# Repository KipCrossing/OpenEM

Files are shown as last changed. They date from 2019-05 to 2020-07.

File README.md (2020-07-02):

# OpenEM Project

--------------------------------------------------------------------------------

This repository contains the Files and code related to the OpenEM project.

See [TODO.md](Info/TODO.md) for the current to do list.

Notes for the H-bridge variation of the setup may be found [here](Testing/README.md)

## Notes Summary

The following are a summary of notes in regards to the development of the OpenEM project; including the materials and methods used.

- Pyboard with micropython
- AD9833 wave generator
- 10 W amplifier
- Matching coils with RF of 17100 Hz
- Rx coil and op-amp grounded to 2.5 volts
- ADC on pyboard 0-3.3v for Rx signal
- ADC on pyboard to record wave from AD9833
- Record both waves onto buffers - x rotations and 10 samples per wave
- Get average of each n samples for all waves
- Use the curve fitting algorithm to get the amplitude and starting phase of the waves
- Calculate the phase shift of the received wave from the gen wave for reference
- Calibrate the primary wave while OpenEM is placed high above the ground
- Subtract Hp from the total input wave (Record Hp values)
- Lower OpenEM to the ground - new readings should be Hs (Amp and sft)
- Send readings to phone over Bluetooth
- Use Open Data Mapper to saves readings and GPS into a file and put coloured pin on the map
- Perform OpenEM survey on the field
- Perform Dualem survey on the field
- Smooth OpenEM data with a 7 point average
- Load data into QGIS
- Interpolate data (kriging) for the field area into rasta files (All dualem con and OpenEM con)
- Compare points of each Raster
- Make a model of Open vs 1mHCPcon & 2mHCPcon
- Discuss

Lessons learnt:

- ADC side Rx coil at the centre wire for more stable reading
- The RF of the Rx coil will change depending on what side the coil is grounded (inner or outer)
- Make coils RIGID
- put choke inductor at the 10 W amplifier to reduce noise from the amplifier
- Don't use a pre-amplifier as it changes the resonant frequency of the receiver coil
- Use a simple non inverting amplifier grounded at 2.5 volts
- Secure all cables so that they don't move
- Place received a coil at distance from the circuitry to avoid feedback noise

## PyBoard with MicroPython

There are several requirements and pre-requisites for the OpenEM project that need to be considered when deciding on the correct microcontroller. These include: High resolution and high sample rate ADC Fast processing power for complex algorithms Common interfaces including; I2C, SPI and UART to drive external hardware and sensors Rapid prototyping Expandable storage for logging The microcontroller that was chosen, as it meets the above criteria, is the PyBoard (Bell 2017). The PyBoard is based on the STM32F405RG ARM micro-processor with an operating frequency of 168 MHz. The ADC's have a 12-bit resolution a sample rate of up to 200 kHz. All common interfaces are included plus several GPIO pins. Further, the PyBoard has a micro SD card slot for expandable storage. Lastly, the PyBoard is powered by MicroPython and is ideal for rapid prototyping.

MicroPython is a Re-write of Python 3 that is designed to run on microcontrollers (reference). Further, python is a commonly used, simple programming language and, as such, is good for showcasing the methods and algorithms used when handling and analysing the data. The MicroPython code for the OpenEm project may be found [here](https://github.com/KipCrossing/OpenEM).

## AD9833 Wave Gen

The first step, after establishing what microcontroller to use, is to generate a sine wave that can be adjusted to match the resonant frequency of the transmitter and receiver coils. Therefore, it is important to select a wave generator with a variable frequency that can be adjusted via a common interface. For this, the AD9833 was selected as is has a frequency range of 0.1 Hz to 12.5 MHz (Qi et al. 2015) and can be controlled over SPI. To set the frequency and wave type (sine, square or triangle) a MicroPython library was made and can be found [here](https://github.com/KipCrossing/Micropython-AD9833). This signal is then amplified to the Transmitter coil.

## Amplifying the signal

One of the objectives with the transmitter coil it to maximise the current flowing through it. According to the law of Biot-Savart [(Pappas 1983)](https://link-springer-com.ezproxy1.library.usyd.edu.au/content/pdf/10.1007%2FBF02721552.pdf), the magnetic flux density is directly proportional to current I

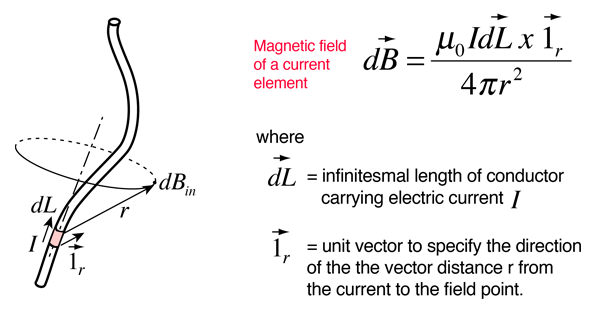
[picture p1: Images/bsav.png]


Therefore, we need an amplifier to supply the current and that will maximise the voltage to get the maximum current.

```
V = I*Z
```

Where Z is the impedance of the coil at frequency f. The working for this may be found [here](https://github.com/KipCrossing/Coil_Physics/blob/master/coil.py).

## OpenEM Frequency

The frequency needs to be chosen whilst considering the following requirements:

- The sample rate of the ADC on the PyBoard and enough samples per wave to get a precise enough estimate of the waves properties (apm and shift)
- The higher the frequency, the higher the Emf (Faraday's law)
- The larger the area of Rx the larger the Emf
- The higher the frequency, the lower the capacitive reactance
- The higher the frequency, the higher the inductive reactance
- The coil needs to have practical dimensions for the resonant frequency

The max sample rate of the pyboard using the `pyb.ADC.read_timed_multi()` method is approximately 200 kHz. The reason multiple ADC channels need to be recorded at once is so that the phase shift, in reference to the original wave (AD9833) can be observed. Further at least 10 samples per wave is deemed as acceptable to get an estimate of the wave properties. Therefore the frequency needs to be less than 20 kHz.

### Resonant Frequency

The resonant frequency of a coil is determined by:

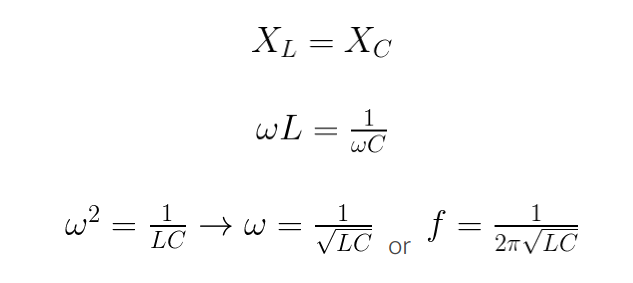
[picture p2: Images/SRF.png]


Where:

- XC = capacitive reactance
- XL = inductive reactance
- C = capacitance
- L = inductance

### Coil Details

Wound on a ferrite core, these are the details of the coil configuration:

- Wire gauge: 0.5 mm
- Coil length: 100 mm (200 turns)
- Number of layers: 20
- Total turns: 40,000
- Ferrite core diameter: 10 mm

Coil Properties:

- RF = 17,100 Hz
- L = 514.3 mH
- R = 12.6 Ohms
- C = 0.16 nF

The Resonant Frequency (**RF**) was obtained by sweeping a wave in an adjacent coil and observing where the amplitude peaked. The Coils Inductance (**L**) and Resistance (**R**) were measured using an [LCR40](https://www.peakelec.co.uk/acatalog/lcr40-atlas-lcr-meter.html). Lastly the capacitance (**C**) was back calculated using the following relation for the RF:

```
RF = 1/(2*math.pi_math.sqrt(Inductance*Capacitance)
```

From here, we may determine the Total Reactance (**Xt**) and the Impedance (**Z**) of the coils using the following equations (ref):

```
def Total_Reactance(self, freq):
  L = 2*np.pi_freq_self.coil_inductance
  C = 1/(2*np.pi_freq_self.coil_capacitance)
  return abs(C-L)

def Impedance(self, freq):
  return np.sqrt(self.coil_resistance**2 + self.Total_Reactance(freq)**2)
```

- Xt: 2913.00 Ohms
- Z = 2913.05 Ohms

Note that the Resistace (**R**) is significantly lower than the Total Reactance (**Xt**) and therefor Xt is the major contributing factor in the Impedance (**Z**). These equations may be found the the [Coil_Physics](https://github.com/KipCrossing/Coil_Physics) repo.

### Coil winding methods

In order to get the correct RF, a frequency sweep generator was set up and the frequency at which the the amplitude was the greatest is the RF. Depending on weather the frequency needs to be higher or lower, the following is done: To get it high - unwind loops. To get lower - wind more loops. Generally, more turns makes the Inductance increase which in turn, makes the makes the RF lower (see above formula for RF). Further, the length of the ferrite core is another factor contributing to the RF of a coil.

This is done with a similar set-up to what will be used in the OpenEM amplification signal. The materials and method are:

- get wave generator -
- Control AD9833 over SPI from the pyboard using this [DRIVER](https://github.com/KipCrossing/Micropython-AD9833)
- amplify the signal with a mini 10 Watt amplifier
- sweep through a range of frequencies to determine which frequency has yields the highest amplitude.

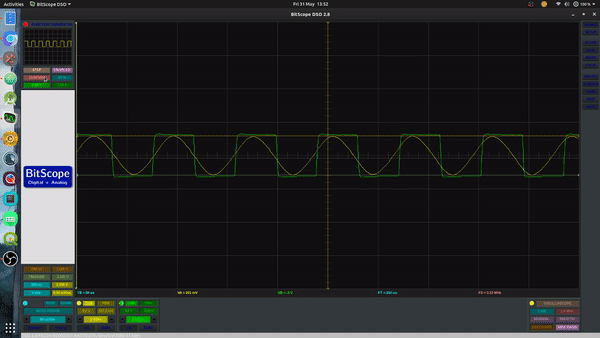
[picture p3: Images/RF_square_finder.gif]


_(insert figure for sweep f vs amp)_

_Note: For consistency, the transmitter coil and the receiver coil are identical so that the RF's are the same for both_

### Wave Generator

Once the RF has been established the wave is then amplified via simila means to how the RF was established. That is: PyBoard -> AD9833 -> AMP -> Tx coil

### Transmitter Coil

### receiver coil

## OpenEM Images

### Image of OpenEM in the field



### Image of the OpenEM being calibrated



### Map showing some example results of the OpenEM



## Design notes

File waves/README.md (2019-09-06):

# A discussion on analysing the data containing the primary and secondary waves

In this section, we will discuss approaches used to obtain our primary and secondary waves from our input data.

# Obtaining the Primary wave (Hp)

First, we obtain a list of data that is a representation of the primary wave that was obtained during calibration.

```python
Hp = [-6583,    580,    7477,    11508,    11147,    6558,    -540,    -7415,    -11523,    -11209]
```

We then approximate the Amplitude and phase shift using:

```python
import specialmath
sm = specialmath.SpecialMath()
(amp, sft) = sm.fit_sin(Hp, 5)
```

Note: the shift `sft` is relative to the transmitted wave and is observer by another ADC From these, we can generate a new the "perfect wave" using:

```python
Hp_fit = sm.gen_sin(10, amp, sft)
```

We can now get the values for the "perfect wave":

```python
>>> print(Hp_fit)
[-6570.65308724154, 550.1017952045793, 7460.736489154883, 11521.623425354583, 11181.64181864582, 6570.6530872415415,-550.1017952045727, -7460.736489154878, -11521.623425354584, -11181.641818645821]
```

And by taking the difference of the two lists, we get the noise:

```python
[-12.34691276, 29.8982048, 16.26351085, -13.62342535, -34.64181865, -12.65308724, 10.1017952, 45.73648915, -1.376574645, -27.35818135]
```

By viewing this data on a graph, it may be shown that the difference is relatively minor:

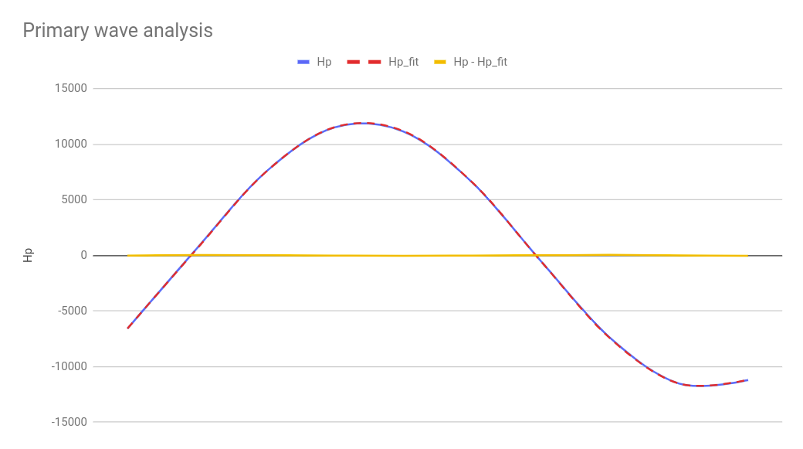
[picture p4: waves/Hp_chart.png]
Hp_chart


Now, the by subtracting the primary wave data from the input data, we should approximate to zero far away from material. When close to material, input signal

# Obtaining the Secondary wave (Hs)

## Method 1

The values of the Amplitude and Phase shift relative to the Tx signal of Hp are captured during calibration. Then when lowered to the ground for readings, a data list is created using the gen_sin() method that represents the primary wave.

```python
sm.hp = sm.gen_sin(10, sm.hp_amp, s1 + sm.hp_sft)
```

This list is then subtracted from the new input signal list (Ht) to get the list representing the secondary wave.

_Note: this method does not take into account changes in the primary signal_

## Method 2

This method requires only the phase shift (relative to the Tx signal) as a reference to the phase of the primary wave. Once the primary wave phase shift is obtained, during calibration, `sm.hp_sft` the unit vector created using the phase angle is taken to be in parallel with the Real axis on the imaginary plane. As Hs will proceed Hp by a quarter wavelength (quadrature), Hs can be taken a the vector parallel to the imaginary vector.

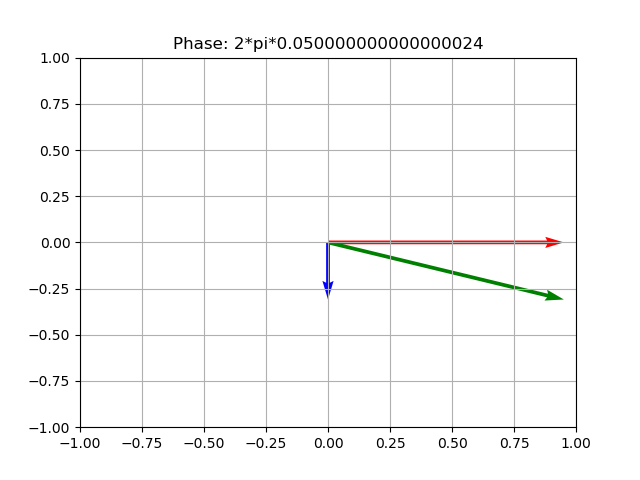
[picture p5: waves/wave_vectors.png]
wave_vector


_(Add lables etc)_

From this, Hp and Hs may easily be extracted from Ht using the trigonometric relationship:

```python
Hs = Ht*np.sin(np.pi*2*phase)
Hp = Ht*np.cos(np.pi*2*phase)
```

Where `phase` is the input phase minus the `sm.hp_sft`.

The above example may be viewed in their sinusoidal form:

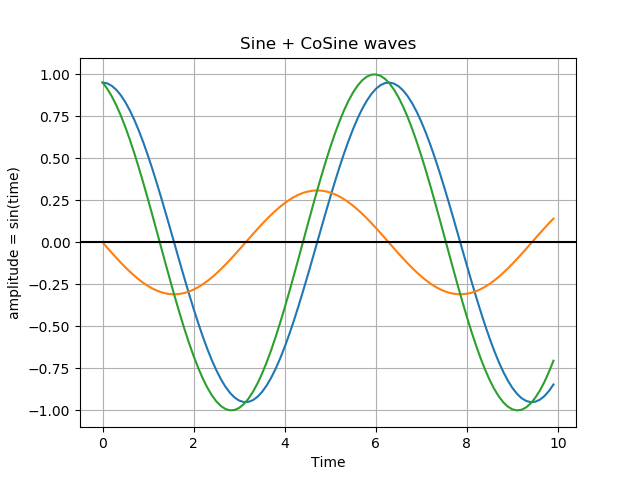
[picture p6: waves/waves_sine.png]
sine


The following formula shown the relationship between the two methods.

formula

See [REF](https://dspguru.com/files/Sum_of_Two_Sinusoids.pdf)

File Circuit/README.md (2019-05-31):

# OpenEM Circuit

This is where I will keep the Fritzing files for the OpenEM project

Version: Fritzing 0.9.3

## Notes:

Just getting started

### TODO

- Fix H-Bridge part
- coil
- Non-inverting amplifier (op amp)
- AD9833
- PyBoard
- Amplifier
- blue-tooth
- temp sensor
- voltage to ADC

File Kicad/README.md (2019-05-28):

# OpenEM Circuit

This is where I will keep the KiCad files for the OpenEM project

Version: KiCad 5.0.2

## Notes:

Just getting started

### TODO

- coil
- Non-inverting amplifier (op amp)
- AD9833
- PyBoard
- Amplifier
- blue-tooth
- temp sensor
- voltage to ADC

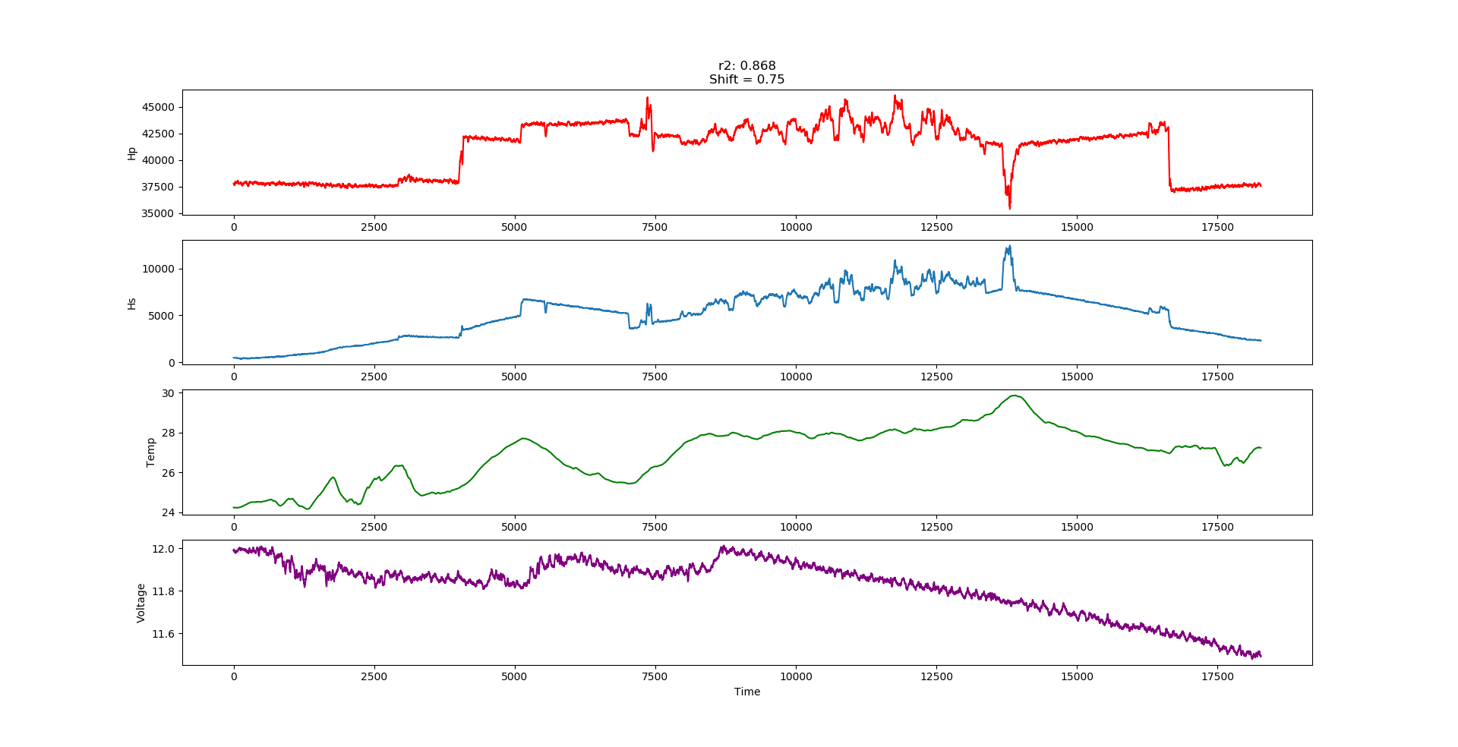
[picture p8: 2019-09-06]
Images/Cobbity9_1.png

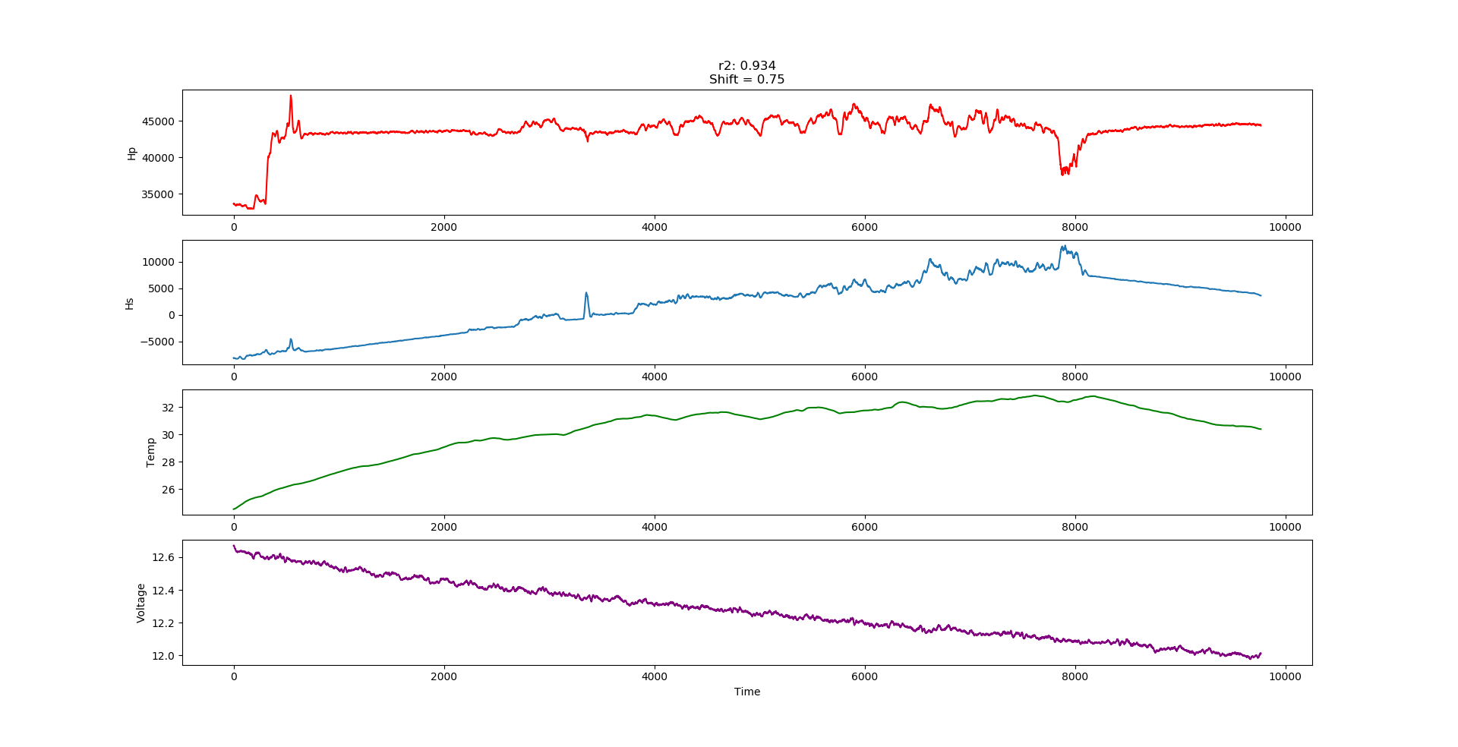
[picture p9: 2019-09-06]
Images/Cobbity9_2.png

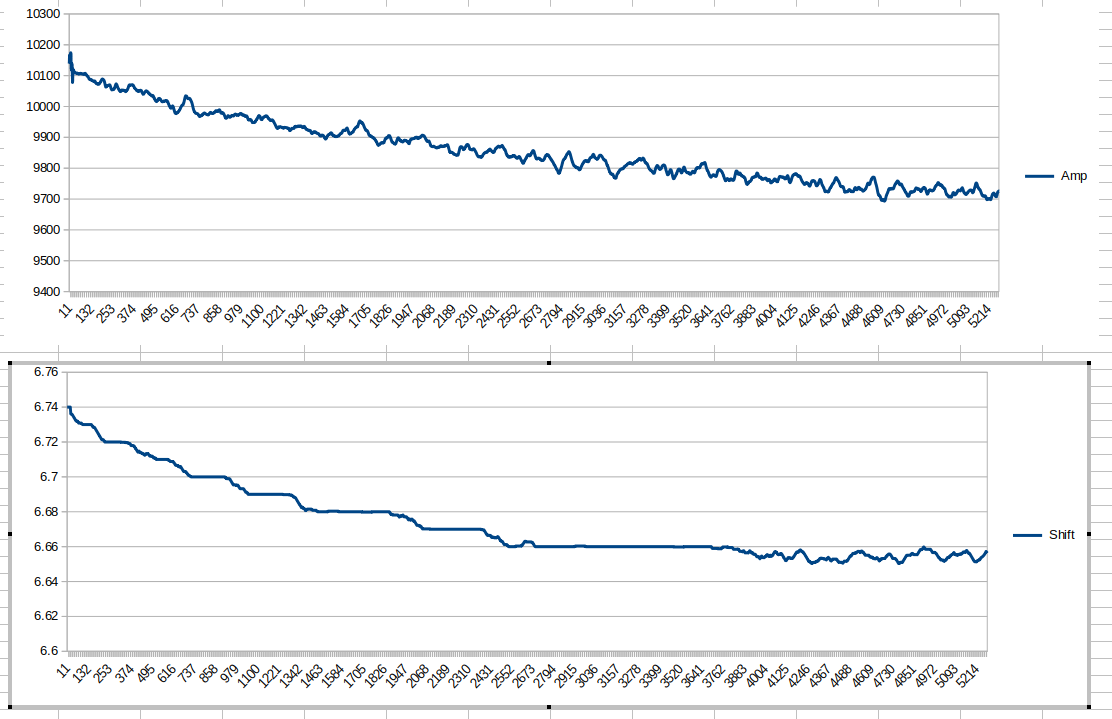
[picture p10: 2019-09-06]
waves/Screenshot from 2019-07-03 22-18-38.png

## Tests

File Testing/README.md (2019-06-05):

# Powering the Transmitter coil with a H-Bridge

This directory to keep notes on powering the Transmitter with a H-Bridge

The current set up is to keep put chokes on the 12v-in and GND-in lines of The H Bridge.

## Outcomes

- Stable input signal
- No voltage drift
- Small amount of drift (maybe noise)

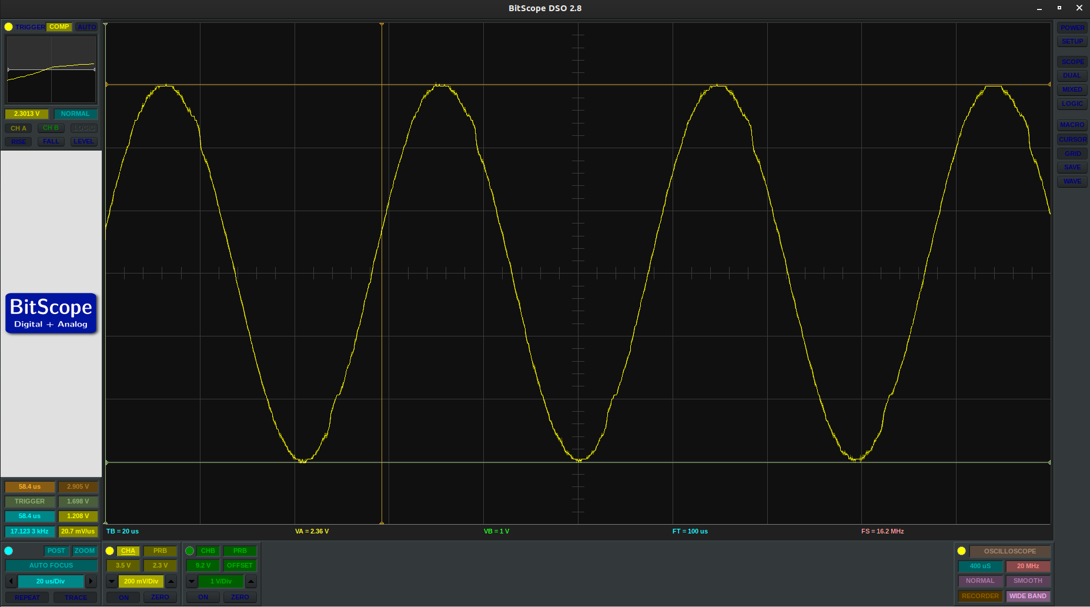
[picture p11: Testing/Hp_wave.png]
 _Input wave at calibration location_

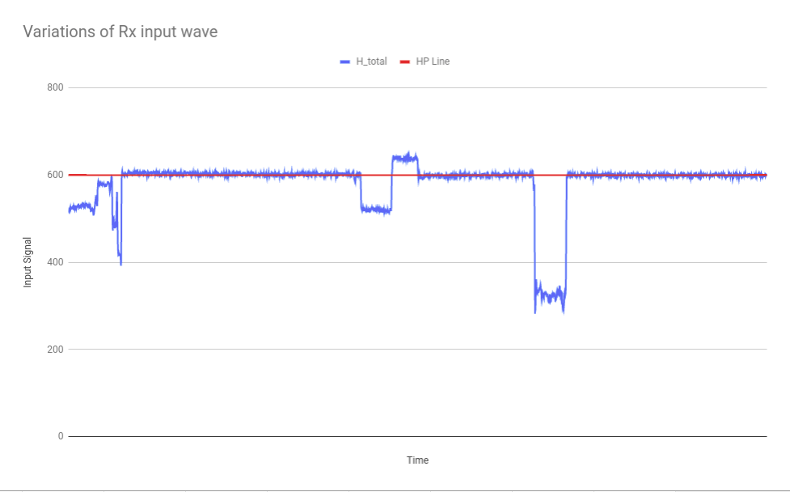
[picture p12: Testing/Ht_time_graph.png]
 _Graph showing the stability of the input signal_

There seems to be no drift in readings over a long amount of time. The standard deviation is about 2.9 for input reading average of 603.0\. _Note: these readings are directly proportional to the value from the ADC_

Notes on above image:

- Where the readings are at about 600, this is when the OpenEM is in the calibration area (no conductive material near it)
- At the beginning this is when the OpenEM is being moved from the work bench
- The 2nd and 3rd variations are at two different location (in more in phase and the other out)
- The last variation is when the oscilloscope is attached and the impedance of the input amplifier changes

Using the method on the same commit, an error occurs only **0.5%** of the time.

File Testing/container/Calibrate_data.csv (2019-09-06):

ID | Amp | Shift | Shift_out | Voltage | Temp | Humidity | Hs | Hp
0 | 39918.54 | 6.8 | 0.4000001 | 11.65521 | 25.56344 | 40.50965 | 9927.341 | 38664.42
1 | 39235.32 | 6.82 | 0.4199996 | 11.73105 | 25.53406 | 40.53407 | 10234.19 | 37877.06
2 | 39817.23 | 6.81 | 0.4099998 | 11.67589 | 25.51804 | 40.589 | 10144.26 | 38503.32
3 | 39831.0 | 6.82 | 0.4200001 | 11.71726 | 25.47532 | 40.62562 | 10389.58 | 38452.12
4 | 39538.26 | 6.81 | 0.4099998 | 11.73105 | 25.41924 | 40.70344 | 10073.19 | 38233.55
5 | 38959.41 | 6.81 | 0.4099998 | 11.66899 | 25.40589 | 40.75838 | 9925.714 | 37673.81
6 | 39249.6 | 6.82 | 0.4199996 | 11.71036 | 25.37919 | 40.78432 | 10237.92 | 37890.85
7 | 39581.61 | 6.820001 | 0.4200006 | 11.67589 | 25.33646 | 40.87587 | 10324.54 | 38211.36
8 | 39159.84 | 6.820001 | 0.4200006 | 11.67589 | 25.30709 | 40.90028 | 10214.53 | 37804.19
9 | 39208.8 | 6.809999 | 0.4099994 | 11.70347 | 25.23766 | 41.0193 | 9989.239 | 37914.97
10 | 39835.59 | 6.81 | 0.4099998 | 11.65521 | 25.19493 | 41.05592 | 10148.94 | 38521.07
11 | 39629.04 | 6.81 | 0.4099998 | 11.71036 | 25.13885 | 41.13375 | 10096.32 | 38321.34
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

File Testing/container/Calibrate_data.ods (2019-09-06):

ID | Amp | Shift | Shift_out | Voltage | Temp | Humidity | Hs | Hp | Hs | Hp | TempAdj |  | HsAdj | 6.8
0 | 39918.54 | 6.8 | 0.4000001 | 11.65521 | 25.56344 | 40.50965 | 9927.341 | 38664.42 | 0 | 39918.54 | 0 | 0 | 0
1 | 39235.32 | 6.82 | 0.4199996 | 11.73105 | 25.53406 | 40.53407 | 10234.19 | 37877.06 | 493.032595956114 | 39232.2221440709 | -0.02938 | -12.3058830036168 | 529.950244966964
2 | 39817.23 | 6.81 | 0.4099998 | 11.67589 | 25.51804 | 40.589 | 10144.26 | 38503.32 | 250.17738839979 | 39816.4440419688 | -0.045400000000001 | -19.0158981744118 | 307.225082923025
3 | 39831 | 6.82 | 0.4200001 | 11.71726 | 25.47532 | 40.62562 | 10389.58 | 38452.12 | 500.517934593829 | 39827.8551116822 | -0.08812 | -36.9092719631969 | 611.24575048342
4 | 39538.26 | 6.81 | 0.4099998 | 11.73105 | 25.41924 | 40.70344 | 10073.19 | 38233.55 | 248.424579727718 | 39537.4795485978 | -0.144200000000001 | -60.3985135848053 | 429.620120482134
5 | 38959.41 | 6.81 | 0.4099998 | 11.66899 | 25.40589 | 40.75838 | 9925.714 | 37673.81 | 244.787581843254 | 38958.6409746012 | -0.157550000000001 | -65.9901928938004 | 442.758160524655
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

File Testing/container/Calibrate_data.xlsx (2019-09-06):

ID | Amp | Shift | Shift_out | Voltage | Temp | Humidity | Hs | Hp | Hs | Hp | TempAdj |  | HsAdj | 6.8
0 | 39918.54 | 6.8 | 0.4000001 | 11.65521 | 25.56344 | 40.50965 | 9927.341 | 38664.42 | 0 | 39918.54 | 0 | 0 | 0
1 | 39235.32 | 6.82 | 0.4199996 | 11.73105 | 25.53406 | 40.53407 | 10234.19 | 37877.06 | 493.032596 | 39232.22214 | -0.02938 | -12.305883 | 529.950245
2 | 39817.23 | 6.81 | 0.4099998 | 11.67589 | 25.51804 | 40.589 | 10144.26 | 38503.32 | 250.1773884 | 39816.44404 | -0.0454 | -19.01589817 | 307.2250829
3 | 39831 | 6.82 | 0.4200001 | 11.71726 | 25.47532 | 40.62562 | 10389.58 | 38452.12 | 500.5179346 | 39827.85511 | -0.08812 | -36.90927196 | 611.2457505
4 | 39538.26 | 6.81 | 0.4099998 | 11.73105 | 25.41924 | 40.70344 | 10073.19 | 38233.55 | 248.4245797 | 39537.47955 | -0.1442 | -60.39851358 | 429.6201205
5 | 38959.41 | 6.81 | 0.4099998 | 11.66899 | 25.40589 | 40.75838 | 9925.714 | 37673.81 | 244.7875818 | 38958.64097 | -0.15755 | -65.99019289 | 442.7581605
6 | 39249.6 | 6.82 | 0.4199996 | 11.71036 | 25.37919 | 40.78432 | 10237.92 | 37890.85 | 493.212039 | 39246.50102 | -0.18425 | -77.17355151 | 724.7326935
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

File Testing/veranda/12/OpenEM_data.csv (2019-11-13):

ID | Amp | Shift | Shift_out | Voltage | Temp | Humidity | CoreTemp | Hs | Hp | Wmean
0 | 3093.811 | 8.15202 | 5.639081 | 13.06888 | 21.1761 | 39.52544 | 42.16 | 2847.722 | -1209.192 | 1295754.0
1 | 3764.885 | 9.6021 | 7.089162 | 13.07922 | 21.16274 | 39.41253 | 41.84 | 961.0996 | -3640.144 | 1296248.0
2 | 3399.86 | 8.56574 | 6.052801 | 13.07922 | 21.14672 | 39.30114 | 41.52 | 2682.745 | -2088.524 | 1296351.0
3 | 1104.803 | 2.21205 | 9.699111 | 13.0344 | 21.14672 | 39.30114 | 42.16 | -1085.118 | -207.6253 | 1296639.0
4 | 1618.813 | 6.835979 | 4.323041 | 13.04819 | 21.10666 | 39.23857 | 42.16 | 1474.571 | 667.9803 | 1296315.0
5 | 2727.046 | 4.585959 | 2.073021 | 13.04819 | 21.10666 | 39.22484 | 41.84 | -722.8647 | 2629.495 | 1296087.0
6 | 3129.389 | 4.76785 | 2.254911 | 13.07577 | 21.10666 | 39.12871 | 41.52 | -480.0041 | 3092.357 | 1296502.0
7 | 2740.987 | 4.79571 | 2.282771 | 13.0413 | 21.07729 | 39.12718 | 41.52 | -372.954 | 2715.495 | 1296022.0
8 | 2324.494 | 4.970399 | 2.45746 | 13.04819 | 21.07729 | 39.11345 | 41.52 | -62.12305 | 2323.664 | 1296860.0
9 | 2307.032 | 5.28468 | 2.771741 | 13.07922 | 21.05058 | 39.234 | 41.84 | 391.9917 | 2273.486 | 1296534.0
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

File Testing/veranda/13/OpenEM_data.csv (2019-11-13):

ID | Amp | Shift | Shift_out | Voltage | Temp | Humidity | CoreTemp | Hs | Hp | Wmean | Freq
0 | 205577.8 | 2.43354 | 9.93354 | 13.48944 | 22.07599 | 56.84902 | 37.36 | -8582.002 | -205398.6 | 1304183.0 | 9235
1 | 205699.4 | 2.433059 | 9.93306 | 13.48255 | 22.03326 | 56.87648 | 38.0 | -8649.111 | -205517.5 | 1304486.0 | 9235
2 | 205766.4 | 2.432511 | 9.93251 | 13.51357 | 22.04929 | 56.85665 | 38.32 | -8722.801 | -205581.5 | 1304225.0 | 9235
3 | 205591.9 | 2.43162 | 9.93162 | 13.47566 | 22.03326 | 56.85359 | 39.28 | -8830.39 | -205402.2 | 1304625.0 | 9235
4 | 205541.9 | 2.43119 | 9.93119 | 13.48255 | 22.04929 | 56.87953 | 39.6 | -8883.665 | -205349.8 | 1304484.0 | 9235
5 | 205433.4 | 2.431689 | 9.931689 | 13.51357 | 22.04929 | 56.86733 | 39.6 | -8814.677 | -205244.2 | 1304796.0 | 9235
6 | 205436.4 | 2.43169 | 9.93169 | 13.46187 | 22.04929 | 56.87953 | 39.92 | -8814.61 | -205247.2 | 1304500.0 | 9235
7 | 205567.6 | 2.43043 | 9.93043 | 13.48255 | 22.04929 | 56.86733 | 40.24 | -8982.806 | -205371.3 | 1304882.0 | 9235
8 | 205511.4 | 2.4321 | 9.9321 | 13.47566 | 22.03326 | 56.88869 | 40.24 | -8764.958 | -205324.4 | 1304654.0 | 9235
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

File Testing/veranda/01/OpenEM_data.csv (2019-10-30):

ID | Amp | Shift | Shift_out | Voltage | Temp | Humidity | CoreTemp | Hs | Hp | Wmean
0 | 132.6416 | 6.94161 | 4.638036 | 13.55839 | 25.99603 | 34.57542 | 44.08 | 29.90711 | -129.226 | 1310730.0
1 | 130.0739 | 5.19838 | 2.894806 | 13.58252 | 25.98268 | 34.55863 | 43.44 | 126.0923 | -31.93674 | 1310616.0
2 | 96.08691 | 4.9129 | 2.609326 | 13.60665 | 25.98268 | 34.55863 | 44.08 | 95.86032 | -6.595168 | 1310779.0
3 | 129.8579 | 0.9792199 | 8.675646 | 13.48944 | 25.98268 | 34.5861 | 44.08 | -96.01147 | 87.43502 | 1310627.0
4 | 113.9455 | 4.56076 | 2.257186 | 13.60665 | 25.96933 | 34.6273 | 44.4 | 112.622 | 17.3167 | 1310816.0
5 | 214.7823 | 4.67806 | 2.374486 | 13.45842 | 25.98268 | 34.5861 | 44.08 | 214.1148 | 16.92077 | 1310611.0
6 | 249.1355 | 4.84638 | 2.542806 | 13.46187 | 25.96933 | 34.57084 | 44.08 | 249.0454 | -6.699862 | 1310809.0
7 | 274.9135 | 5.04029 | 2.736716 | 13.44118 | 25.96933 | 34.59983 | 44.08 | 271.8783 | -40.73813 | 1310554.0
8 | 141.8548 | 5.62267 | 3.319096 | 13.43429 | 25.96933 | 34.5861 | 44.08 | 123.4794 | -69.82563 | 1310789.0
9 | 328.9684 | 4.9389 | 2.635326 | 13.53771 | 25.95331 | 34.61204 | 44.08 | 327.78 | -27.93775 | 1310612.0
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

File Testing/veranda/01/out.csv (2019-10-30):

i0 | i1 | i2 | i3 | i4 | i5 | i6 | i7 | i8 | i9
9261.001 | 17893.0 | 19844.0 | 14236.0 | 3019.0 | -9275.001 | -18043.0 | -19818.0 | -14115.0 | -3002.0
19314.25 | 12485.25 | 693.25 | -11342.75 | -18921.75 | -19285.75 | -12417.75 | -643.75 | 11221.25 | 18897.25
1557.625 | 13301.63 | 19623.62 | 18497.62 | 10419.63 | -1775.375 | -13207.37 | -19502.37 | -18494.38 | -10420.37
-14897.75 | -19971.75 | -17557.75 | -8245.749 | 4082.25 | 14816.25 | 19811.25 | 17514.25 | 8466.25 | -4016.75
16218.75 | 6191.75 | -6371.25 | -16465.25 | -20143.25 | -16265.25 | -6021.25 | 6466.75 | 16363.75 | 20024.75
-8532.75 | -17605.75 | -19966.75 | -14718.75 | -3885.75 | 8480.25 | 17578.25 | 20061.25 | 14715.25 | 3875.25
19448.87 | 13014.87 | 1435.875 | -10611.13 | -18645.12 | -19442.12 | -12988.13 | -1382.125 | 10615.87 | 18552.87
969.75 | 12689.75 | 19353.75 | 18673.75 | 11001.75 | -887.2499 | -12572.25 | -19318.25 | -18784.25 | -11126.25
-19785.25 | -17916.25 | -8981.25 | 3344.75 | 14430.75 | 19847.75 | 17683.75 | 8997.75 | -3254.25 | -14368.25
-6847.75 | 5610.25 | 15725.25 | 20075.25 | 16784.25 | 6873.25 | -5716.75 | -16000.75 | -19955.75 | -16547.75
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

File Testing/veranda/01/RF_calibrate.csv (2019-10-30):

Freq | Amp | Shift | tim_freq | temp
9220 | 166257 | 2.298 | 92206.36 | 26.02541
Hp | 166204.4 | 2.303574

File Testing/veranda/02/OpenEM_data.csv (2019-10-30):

ID | Amp | Shift | Shift_out | Voltage | Temp | Humidity | CoreTemp | Hs | Hp | Wmean
0 | 250.8576 | 8.78389 | 6.500241 | 13.55839 | 24.63416 | 33.38522 | 44.72 | -202.9704 | -147.4197 | 1312474.0
1 | 61.337 | 4.63857 | 2.354922 | 13.56528 | 24.63416 | 33.38522 | 44.72 | 61.08234 | 5.583465 | 1312367.0
2 | 132.7418 | 6.99278 | 4.709131 | 13.53081 | 24.63416 | 33.3547 | 44.72 | 24.12483 | -130.5311 | 1312556.0
3 | 127.7085 | 1.491201 | 9.207553 | 13.53771 | 24.64751 | 33.3547 | 44.4 | -60.99224 | 112.2026 | 1312399.0
4 | 210.2226 | 2.601511 | 0.3178623 | 13.56873 | 24.63416 | 33.3547 | 44.4 | 41.70683 | 206.0438 | 1312497.0
5 | 188.2393 | 1.40524 | 9.121592 | 13.5446 | 24.63416 | 33.36843 | 44.4 | -98.69827 | 160.2894 | 1312341.0
6 | 459.9802 | 0.1581001 | 7.874452 | 13.52047 | 24.63416 | 33.33944 | 44.72 | -447.3079 | 107.2261 | 1312706.0
7 | 185.7681 | 3.06568 | 0.782032 | 13.38603 | 24.60479 | 33.41268 | 44.72 | 87.65098 | 163.7898 | 1312322.0
8 | 146.9707 | 0.0606184 | 7.77697 | 13.42739 | 24.60479 | 33.36691 | 44.72 | -144.7508 | 25.44775 | 1312456.0
9 | 357.5709 | 0.8608294 | 8.577181 | 13.40671 | 24.59144 | 33.3959 | 44.72 | -278.7526 | 223.9507 | 1312241.0
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

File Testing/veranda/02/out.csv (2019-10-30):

i0 | i1 | i2 | i3 | i4 | i5 | i6 | i7 | i8 | i9
-4994.625 | 7429.375 | 16906.37 | 19952.37 | 15206.38 | 4780.375 | -7473.625 | -16869.63 | -19712.62 | -15224.62
-17967.88 | -19694.87 | -13779.88 | -2591.875 | 9616.125 | 17990.12 | 19471.12 | 13644.12 | 2717.125 | -9403.875
12062.88 | 424.875 | -11456.12 | -18859.12 | -19002.12 | -12054.13 | -470.125 | 11297.87 | 18843.87 | 19211.87
12963.87 | 19494.87 | 18394.87 | 10251.87 | -1890.125 | -13220.12 | -19447.12 | -18224.12 | -10192.12 | 1867.875
-17427.37 | -8199.375 | 4128.625 | 14717.62 | 19768.62 | 17243.62 | 8292.624 | -3950.375 | -14745.37 | -19828.37
6164.875 | 16113.87 | 19886.87 | 16119.87 | 6105.875 | -6218.125 | -16127.12 | -19892.12 | -16017.12 | -6137.125
-19739.75 | -14719.75 | -3985.75 | 8410.251 | 17412.25 | 19825.25 | 14479.25 | 3938.25 | -8252.749 | -17366.75
1762.25 | -10276.75 | -18342.75 | -19478.75 | -13099.75 | -1697.75 | 10378.25 | 18446.25 | 19446.25 | 12863.25
19193.25 | 18736.25 | 11182.25 | -571.75 | -12028.75 | -19121.75 | -18793.75 | -11396.75 | 594.25 | 12206.25
-9368.0 | 2844.0 | 13869.0 | 19707.0 | 17804.0 | 9245.0 | -2849.0 | -13827.0 | -19547.0 | -17878.0
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

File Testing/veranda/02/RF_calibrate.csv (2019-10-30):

Freq | Amp | Shift | tim_freq | temp
9220 | 165968 | 2.286 | 92206.36 | 24.66087
Hp | 166205.2 | 2.283648

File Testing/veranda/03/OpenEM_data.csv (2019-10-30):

ID | Amp | Shift | Shift_out | Voltage | Temp | Humidity | CoreTemp | Hs | Hp | Wmean
0 | 242.0164 | 5.50236 | 3.103526 | 13.30329 | 23.60609 | 34.03983 | 41.52 | 89.59044 | 224.8232 | 1305137.0
1 | 91.61942 | 7.97645 | 5.577615 | 13.32397 | 23.60609 | 33.99863 | 41.2 | 85.6515 | -32.52596 | 1304788.0
2 | 498.5015 | 4.225551 | 1.826716 | 13.38947 | 23.62211 | 33.98489 | 41.52 | -204.6505 | 454.5568 | 1304899.0
3 | 503.3307 | 1.88478 | 9.485946 | 13.35155 | 23.60609 | 34.01236 | 42.16 | -477.3037 | -159.7587 | 1304811.0
4 | 510.2356 | 3.07953 | 0.6806953 | 13.35155 | 23.59274 | 34.00931 | 41.52 | -464.2761 | 211.632 | 1305049.0
5 | 413.9471 | 9.240601 | 6.841766 | 13.31708 | 23.57939 | 33.98184 | 41.52 | 166.3616 | -379.0462 | 1304775.0
6 | 341.6931 | 4.78344 | 2.384605 | 13.4136 | 23.59274 | 34.00931 | 41.52 | -24.7527 | 340.7954 | 1304981.0
7 | 402.8098 | 2.53332 | 0.1344852 | 13.35155 | 23.56603 | 33.99405 | 41.84 | -401.3726 | 33.99677 | 1304756.0
8 | 210.1019 | 4.266981 | 1.868146 | 13.39292 | 23.55001 | 34.03525 | 41.52 | -81.23772 | 193.7608 | 1305026.0
9 | 291.6549 | 5.44567 | 3.046835 | 13.35155 | 23.55001 | 34.00778 | 42.16 | 98.24876 | 274.6084 | 1304630.0
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

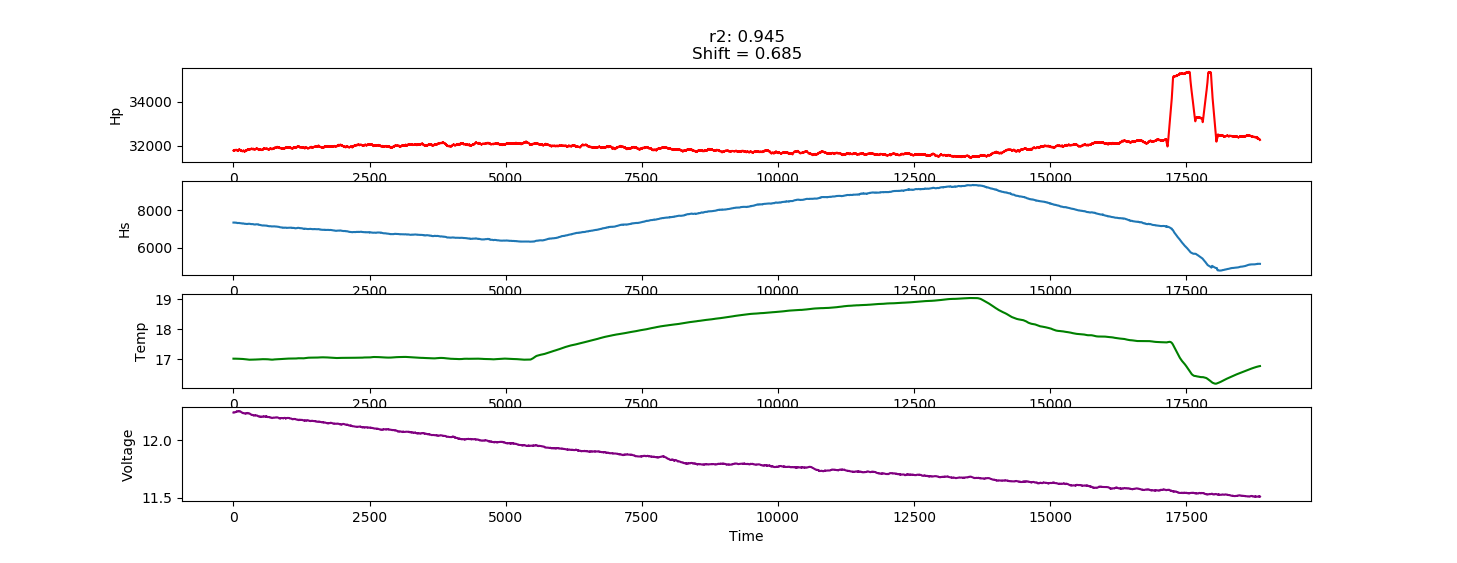
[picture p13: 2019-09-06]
Testing/Temp/Temp_test4_6.85.png

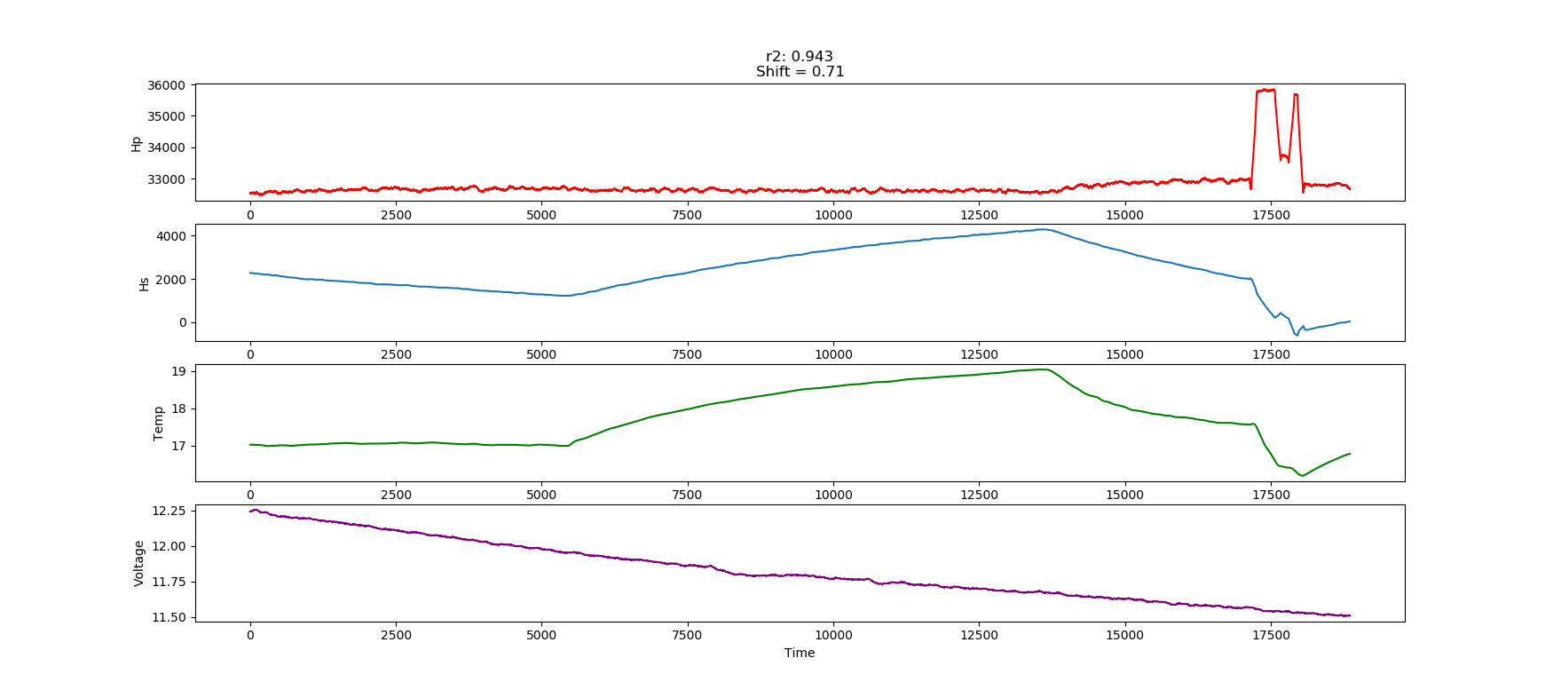
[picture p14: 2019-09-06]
Testing/Temp/Temp_test4_7.5.png

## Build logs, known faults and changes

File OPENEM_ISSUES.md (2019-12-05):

# Design Issues of the OpenEM

The following is a brief statement explaining issues that have arisen during my research into designing the OpenEM; a Low-Cost EMI sensor.

## Intro

The basic idea of electromagnetic induction (EMI) frequency domain (FD) sensors is that a sinusoidal current is introduced into a coil that produces a magnetic field (Ampere's Law) whose magnitude is sinusoidal and therefore produces an electric field (maxwell-faraday equation) that causes eddy currents to be induced in nearby mediums (due to the electromotive force and the electrical resistance of medium). These sinusoidal eddy currents produce a secondary magnetic field that precedes the first (primary) magnetic field by 90 degrees and is said to be in quadrature. Both changing magnetic fields induce an electromotive force (measured in volts) in a second coil (receiver coil) which forms the basis of the input signal.



_Image 1: sine waves of the primary (green) and secondary (orange) signals_



_Image 2: vectors of the primary (red) and secondary (purple) signals_

The input signal is then separated into the primary wave and the secondary wave via quadrature demodulation. The secondary wave is used to calculate the apparent electrical conductivity (ECa) via McNeil's equation and will be inversely proportional to the electrical resistivity of the nearby medium. Changes in the primary wave are proportional to changes in the magnetic susceptibility of the nearby medium; as the relative permeability of the medium impacts the magnetic field. The 'depth of penetration', which is an estimate of the average depth of the origins of the secondary magnetic field, is determined by the geometry of both coils in relation to each other and the nearby medium (in our case, the ground). With common configurations (eg; horizontal and vertical dipole) the depth of penetration of proportional to the intercoil spacing (distance between the transmitter and receiver coil).

## Current Setup

I wanted to start with using a vertical dipole configuration as it is the most basic and has been shown to have the largest depth of penetration (0.7*intercoil spacing). For precision agricultural purposes the intercoil spacing is required to be at least 1m to get subsoil measurements. When the intercoil spacing is small, the magnetic field strength at the receiver coil is large, however, when the intercoil spacing is increased, the magnetic field decreases exponentially in relation to the [Biot-Savart Law](Images/bsav.png).

Although electrical signals can be amplified, if they are much lower than electrical noise (environmental and instrumental) techniques must be employed to overcome the low signal to noise ratio. I used a range of techniques, including analogue and digital filter, using ferrite cores, curve fitting algorithms and operating at the coils resonant frequency. I ran a field survey and got an r2 of 74.5% and concluded that I was on the right track; [see here for results](https://github.com/KipCrossing/EMI_Field).

## Issues and Theorizing

The problems started to arise when changes in temperature would directly affect the outputs (problem 1). Although this can be expected, the variations were large and irregular. My theory is that the variations in temperature change the permeability of the ferrite coil core. This change in permeability affects the induction of the coil which in turn affects the resonant frequency of the coil. Therefore, the magnitude of the input signal may increase or decrease depending on whether the resonant frequency is higher or lower than the operating frequency. A temperature sensor was placed near the receiver coil in an attempt to identify a relationship between the change in temperature and the variations in input signal magnitude. During data collection, I noticed that the reading would change simply by being near the OpenEM or if the OpenEM was near plants. After months of investigation, I concluded that it was due to an electrical field that is present due to an electrical potential of the Transmitter coil, as the varies from peak to peak, and the grounded receiver coil (problem 2). As the OpenEM passes close by plants, the electric field lines are redirected through the plants as they have a higher permittivity than air. In an attempt to stop presence of the electric field, I created Faraday cages to surround each coil. Now, when placed near organic matter (plants, trees), there are no variations. I continued to work on the temperature problem.

It was found that for the relationship between temperature and input signal magnitude to be found, a large amount of data is required; [see here](/Testing/).

Due to the complex relationship between temperature and input signal magnitude, a model was extremely difficult to be established. I had a chat with a professor from the physics department who suggested that the operating frequency should be far away from the resonant frequency such that the relationship between temperature and the resonant frequency is significantly more linear then operating near the resonant frequency. The problem with this technique is that the signal-to-noise ratio would decrease below practical levels.

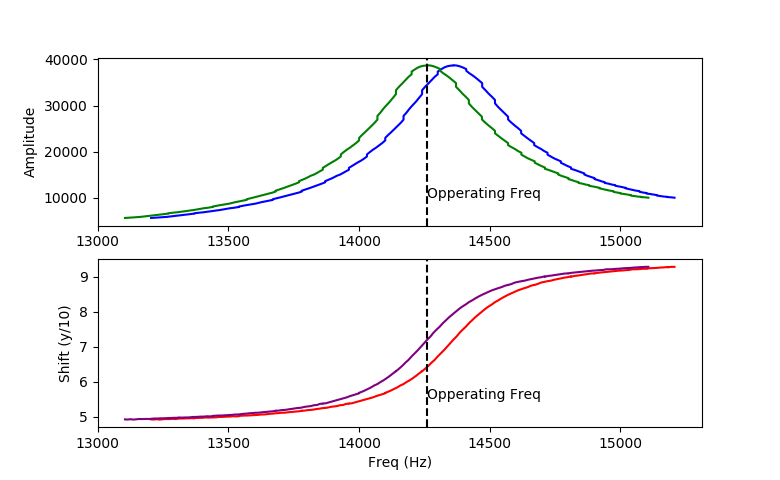
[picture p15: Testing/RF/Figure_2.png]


Further, during constant temperatures, when low into the ground and the secondary field is extracted via quadrature demodulation, the variations in the secondary field were significantly small; Much smaller than that which is predicted via McNeil's equation. This observation led me to believe that the Faraday cages were insufficient in preventing an electric field between the transmitter and receiver coils. Although the Faraday cages did stop variations in the electric field, they didn't stop the presence of an electric field. Instead, the electric field is redirected through the timber frame, as timber has a permeability 4 to 6 times greater than air.



## Closing Remarks

I'm sure there are more techniques and methods for reducing the electric field strength (ie through the use of dielectric materials), however this is far outside my field of expertise. In order to solve these problems, an in-depth knowledge of the permeability and permittivity of materials and tools to detect electric and magnetic fields are required; both of which I do not have. I would need to start practising a whole new discipline of practical physics.

Lastly, my initial assumptions did not consider the presence of an electric field. Therefore, when designing the transmitter coil, a large number of turns was assumed to be desirable as it is proportional to the magnetic field strength. However, the number of turns is also proportional to the electric field strength. I would have to redesign the transmitter coil to account for this.

Considering the small time frame until the due date of my thesis, the gaps in my knowledge and tooling and realistic potential for further unforeseen challenges, I have decided to discontinue work on this project, put it on the shelf and terminate my PhD.

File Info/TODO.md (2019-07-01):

# TO DO LIST

- [x] Wind coil for 17100 Hz
- [x] Use RF circuit to check RF
- [ ] Make it 12 SPW
- [ ] Check both amplifiers (easy connect)
- [ ] Check different sweeps
- [ ] Output max and min ADC readings
- [x] Measure voltage [circuit](https://startingelectronics.org/articles/arduino/measuring-voltage-with-arduino/)

- [ ] Show Hp vs freq graph (For 17100 Hz coil)

- [ ] Get data for `Ht - Hp = Hs` curves

- [ ] Add temperature sensor: [BME280](https://github.com/catdog2/mpy_bme280_esp8266)

- [ ] Do Hp vs temp

- [ ] Do voltage vs Hp test & find relationship

- [ ] Find temp relationship

- [ ] Do Hs vs temp

- [ ] Large Cobbity test

- [ ] Larger field test with ECe (Cores)

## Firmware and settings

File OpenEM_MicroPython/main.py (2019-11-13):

import sht31
import machine
import pyb
import array
import math
import utime
from pyb import Pin, Timer
from ad9833 import AD9833
from pyb import Pin
from pyb import SPI
from specialmath import SpecialMath


print("(Main program started)")


blueled = pyb.LED(4)
greenled = pyb.LED(1)

# Wave gen
ss = Pin('Y5', Pin.OUT_PP)
spi = SPI(2, SPI.MASTER, baudrate=9600, polarity=1, phase=0, firstbit=SPI.MSB)
wave = AD9833(spi, ss)

# Bluetooth
blue_uart = pyb.UART(6, 9600)
blue_uart.init(9600, bits=8, stop=1, parity=None)

# Temp sensor
SCLpin = 'Y9'
SDApin = 'Y10'
i2c = machine.I2C(sda=machine.Pin(SDApin), scl=machine.Pin(SCLpin), freq=400000)
sht31sensor = sht31.SHT31(i2c)


# Initial variables
spw = 10        # Samples per wave
WAVES = 500      # Number of waves to take an average from
freq = 9000    # Frequency in Hz

# send wave
wave.set_freq(freq)
wave.set_type(0)
wave.send()

# check temp sensor
sht31_t, sht31_h = sht31sensor.get_temp_humi()

wait = True
while wait:
    print('Blue Out:')
    if b'BTM-U' == blue_uart.read():
        print("Start")
        wait = False
    pyb.delay(1000)


# pyb.repl_uart(blue_uart)

blue_uart.write("Warming up!\n")


blue_uart.write("Started")


utime.sleep(2)

wave.set_freq(freq)
wave.set_type(0)
wave.send()


# Timers for ADC's
adc1 = pyb.ADC(pyb.Pin.board.Y11)  # create an ADC on pin X11
adc2 = pyb.ADC(pyb.Pin.board.X4)  # create an ADC on pin X4

adc_voltage = pyb.ADC(pyb.Pin.board.Y12)

voltage = (adc_voltage.read()/4096)*14.12


adcall = pyb.ADCAll(12, 0x70000)  # 12 bit resolution, internal channels
coretemp = adcall.read_core_temp()

# tim = pyb.Timer(8, freq=200000)        # Create timer
# buf1 = bytearray(WAVES*spw)  # create a buffer
# buf2 = bytearray(WAVES*spw)  # create a buffe
# # read analog values into buffers at 100Hz (takes one second)
# pyb.ADC.read_timed_multi((adc1, adc2), (buf1, buf2), tim)


sm = SpecialMath()

(sm.hp_amp, sm.hp_sft) = (0, 0)

# Output File
outfile = open('out.csv', 'w')
outfile.write("i0,i1,i2,i3,i4,i5,i6,i7,i8,i9,\n")
outfile.close()


def record(f, tim):
    # tim = pyb.Timer(8, freq=f*spw)        # Create timer
    # bytearray(WAVES*spw)  # create a buffer
    buf1 = array.array('H', (0 for i in range(WAVES*spw)))
    buf2 = array.array('H', (0 for i in range(WAVES*spw)))  # create a buffe
    # read analog values into buffers at 100Hz (takes one second)

    tcheck = pyb.ADC.read_timed_multi((adc1, adc2), (buf1, buf2), tim)
    # print(tcheck)

    listc = []

    for i in range(spw):
        listc.append(0)
    count = 0
    for n in range(len(buf1)):
        if count > spw-1:
            count = 0
        listc[count] += buf1[n]
        count += 1
    buf1 = None
    listd = []
    for i in range(spw):
        listd.append(0)
    count = 0
    for n in range(len(buf2)):
        if count > spw-1:
            count = 0
        listd[count] += buf2[n]
        count += 1
    # (a,s) = sm.fit_sin(listd,6)
    buf1 = None
    (a1, s1) = sm.fit_sin(listc, 6)
    # print("-")
    data_mean = sm.mean(listd)
    # print(data_mean)
    for d in range(0, len(listd)):
        listd[d] -= data_mean

    # total wave - Hp to get Hs
    if sm.hp_amp:
        sm.hp = sm.gen_sin(10, sm.hp_amp, s1 + sm.hp_sft)
        listout = [x - y for x, y in zip(listd, sm.hp)]
    else:
        listout = listd
    # print(listout)
    # outtext = ''
    # for d in listout:
    #     outtext += str(d)+','
    # outfile = open('out.csv', 'a')
    # outfile.write(outtext+"\n")
    # outfile.close()

    (a2, s2) = sm.fit_sin(listout, 6)
    # print(listout)
    # print('Hp - Amp: %f  Sft: %f' % (a1,s1))
    # print('Hs - Amp: %f  Sft: %f' % (a2,s2))
    # print(s2-s1)

    if s2-s1 < 0:
        return(a1, a2, s2-s1 + spw, data_mean)
    else:
        return(a1, a2, s2-s1, data_mean)


'''
outfile = open('RF_calibrate.csv', 'w')
outfile.write("Freq,Amp,Shift,tim_freq,temp,meanW\n")
outfile.close()

while True:
    step_list = [1000, 100, 10, 1]
    mid = 9000
    max_amp = 0
    max_freq = 0
    max_sft = 0
    tim_freq = 1
    target_sft = 100
    RF_range_file = open("FR_range.csv", 'w')
    RF_range_file.write("Freq,Amp,Shift\n")
    for step in step_list:
        for i in range(-5, 6):
            f = mid + i*step
            if step != 1 and step != 2:
                tim = pyb.Timer(8, freq=f*spw)
                freq = int(tim.freq()/float(spw))
            else:
                freq = f
            wave.set_freq(freq)
            wave.send()
            pyb.delay(50)
            greenled.toggle()
            # blue_uart.write("Checking: {}\n".format(freq))
            ampl = []
            sftl = []
            ml = []
            for j in range(4):
                (or_amp, amp, sft, m) = record(freq, tim)
                ampl.append(amp)
                sftl.append(sft)
                ml.append(m)
            outline = "{},{},{}".format(freq, sm.mean(ampl), sm.mean(sftl))
            RF_range_file.write(outline + "\n")
            if sm.mean(ampl) > max_amp:
                max_amp = sm.mean(ampl)
                max_freq = wave.freq
                max_sft = round(sm.mean(sftl), 3)
                tim_freq = tim.freq()
                max_m = sm.mean(ml)
        mid = max_freq

    sht31_t, sht31_h = sht31sensor.get_temp_humi()
    outfile = open('RF_calibrate.csv', 'a')
    output = "{},{},{}".format(max_freq, int(max_amp), max_sft)
    outfile.write(output+",{},{},{}\n".format(tim_freq, sht31_t, max_m))
    blue_uart.write(output)
    print(output)
    blueled.toggle()
    greenled.toggle()
    outfile.close()
    RF_range_file.close()





count = 0

callibrate = []
Hp_prev = 0
calivbate = True

c_amp = 0
c_sft = 0


freq = max_freq
wave.set_freq(freq)
wave.send()
pyb.delay(2000)
blue_uart.write('\nTimer freq: {}'.format(tim_freq))


tim = pyb.Timer(8, freq=tim_freq)
pyb.delay(2000)


ampl = []
sftl = []
for j in range(15):
    (or_amp, amp, sft, m) = record(freq, tim)
    ampl.append(amp)
    sftl.append(sft)
    blue_uart.write("Calibrate: {}%".format(j))
    print(amp, sft)
(sm.hp_amp, sm.hp_sft) = (sm.mean(ampl), sm.mean(sftl))

outfile = open('RF_calibrate.csv', 'a')
outfile.write("Hp,{},{}\n".format(sm.hp_amp, sm.hp_sft))

blue_uart.write("Calibrated! \nAmp: {} \nShift {}".format(sm.hp_amp, sm.hp_sft))


'''


# Output File
outfile = open('OpenEM_data.csv', 'w')
outfile.write("ID,Amp,Shift,Shift_out,Voltage,Temp,Humidity,CoreTemp,Hs,Hp,Wmean,Freq\n")
outfile.close()

amp_roll = []
sft_roll = []
count = 0


sht31_t, sht31_h = sht31sensor.get_temp_humi()

cal_info = [[13.8, 15.8, 9271, 92715.23, 2.515, 2.327],
            [15.8, 17.3, 9261, 92613.0, 2.52, 2.338],
            [17.3, 18.4, 9256, 92561.98, 2.527, 2.435],
            [18.4, 21.2, 9246, 92460.1, 2.576, 2.347],
            [21.2, 22.5, 9235, 92358.44, 2.5, 2.387],
            [22.5, 24.2, 9225, 92256.99, 2.514, 2.332],
            [24.2, 26, 9215, 92155.79, 2.499, 2.345],
            [26, 28.1, 9205, 92054.8, 2.514, 2.337],
            [28.1, 31, 9195, 91954.02, 2.52, 2.35],
            [31, 32.5, 9185, 91853.47, 2.476, 2.346]]


for dat in cal_info:
    lower_t = dat[0]
    upper_t = dat[1]
    if sht31_t >= lower_t and sht31_t < upper_t:
        freq = dat[2]
        tim_freq = dat[3]

wave.set_freq(freq)
wave.send()
tim = pyb.Timer(8, freq=tim_freq)

while True:
    sht31_t, sht31_h = sht31sensor.get_temp_humi()
    for dat in cal_info:
        lower_t = dat[0]
        upper_t = dat[1]
        lower_s = dat[5]
        upper_s = dat[4]
        if sht31_t >= lower_t and sht31_t < upper_t:
            freq = dat[2]
            tim_freq = dat[3]
            grad = ((upper_s-lower_s)/(upper_t-lower_t))
            b = lower_s - grad*lower_t
            sm.hp_sft = 2.5

    wave.set_freq(freq)
    wave.send()
    tim = pyb.Timer(8, freq=tim_freq)
    print("------------------------------" + str(freq))
    blueled.toggle()
    ampl = []
    sftl = []
    ml = []
    for j in range(4):
        (or_amp, amp, sft, m) = record(freq, tim)
        print(amp)
        ampl.append(amp)
        sftl.append(sft)
        ml.append(m)
    ampm = sm.mean(ampl)
    sftm = sm.mean(sftl)
    mm = sm.mean(ml)

    sm.hp_amp = 0  # -0.5052571963643163*mm + 881049.9512239427

    coretemp = adcall.read_core_temp()
    voltage = (adc_voltage.read()/4096)*14.12 + 1

    if sft - sm.hp_sft < 0:
        sft_out = sft - sm.hp_sft + spw
    else:
        sft_out = sft - sm.hp_sft

    Hs = amp*math.sin(math.pi*2*sft_out/spw)
    Hp = -amp*math.cos(math.pi*2*sft_out/spw)

    amp_roll.append(ampm)
    sft_roll.append(sftm)
    if len(amp_roll) > 4:
        amp_roll.pop(0)
        sft_roll.pop(0)

    out_string = "%s, %s, %s, %s, %s, %s, %s, %s, %s, %s, %s, %s\n" % (count,
                                                                       amp,
                                                                       sft,
                                                                       sft_out,
                                                                       voltage,
                                                                       sht31_t,
                                                                       sht31_h,
                                                                       coretemp,
                                                                       Hs,
                                                                       Hp,
                                                                       m,
                                                                       freq)

    print(out_string)
    outfile = open('OpenEM_data.csv', 'a')
    outfile.write(out_string)
    outfile.close()

    blue_uart.write('%s, %s, %s' % (
        count,
        int(sm.mean(amp_roll)),
        sm.mean(sft_roll)))

    count += 1

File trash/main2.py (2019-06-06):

# This is for testing the Hbridge

import pyb
import stm

# Using TIM2 and TIM5 because they correspond to AFs on X1 (TIM2 CH1) & X2 (TIM5 CH2)
# Choose prescaler/period values make sense for sample rate etc.
k = []
for i in range(200):
    tim2 = pyb.Timer(2, prescaler=0, period=490)  # 20 kHz for ADC
    ch2_1 = tim2.channel(1, pyb.Timer.IC, pin=pyb.Pin.board.X1, polarity=pyb.Timer.FALLING)
    # print(tim2.freq())
    PER = 4909
    tim5 = pyb.Timer(5, prescaler=0, period=PER)  # 2 kHz for PWM
    ch5_2 = tim5.channel(2, pyb.Timer.IC, pin=pyb.Pin.board.X2, polarity=pyb.Timer.FALLING)
    # print(tim5.freq())
    # Additional config to make TIM2 gated on TI1 (i.e. channel 1)
    smcr = stm.mem16[stm.TIM2 + stm.TIM_SMCR]
    smcr &= 0b1111111110001000
    smcr |= 0b0000000001010101   # TS = 101 (TI1), SMS = 101 (Gated)
    stm.mem16[stm.TIM2 + stm.TIM_SMCR] = smcr

    # Additional config to make TIM5 gated on TI2 (i.e. channel 2)
    smcr = stm.mem16[stm.TIM5 + stm.TIM_SMCR]
    smcr &= 0b1111111110001000
    smcr |= 0b0000000001100101   # TS = 110 (TI2), SMS = 101 (Gated)
    stm.mem16[stm.TIM5 + stm.TIM_SMCR] = smcr

    ch5_3 = tim5.channel(3, pyb.Timer.PWM, pin=pyb.Pin.board.X3, polarity=pyb.Timer.FALLING)
    ch5_4 = tim5.channel(4, pyb.Timer.PWM_INVERTED, pin=pyb.Pin.board.X4,
                         polarity=pyb.Timer.FALLING)
    ch5_3.pulse_width_percent(50)  # 50% duty cycle
    tim2.counter(490)
    tim5.counter(PER)

    tim14 = pyb.Timer(14, freq=20)
    # print(tim14.period())
    tim14.counter(0)
    ch14_8 = tim14.channel(1, pyb.Timer.OC_FORCED_ACTIVE, pin=pyb.Pin.board.X8)
    ch14_8 = tim14.channel(1, pyb.Timer.OC_INACTIVE, pin=pyb.Pin.board.X8)
    ch14_8.compare(tim14.period())
    print(tim14.counter())
    print(ch14_8.compare())

    adc_X5 = pyb.ADC(pyb.Pin.board.X5)
    adc_X6 = pyb.ADC(pyb.Pin.board.X6)
    buf = bytearray(201)
    tim14.counter(1)
    adc_X5.read_timed(buf, tim2)  # Blocks on the USER button
    ch14_8 = tim14.channel(1, pyb.Timer.OC_FORCED_ACTIVE, pin=pyb.Pin.board.X8)
    tim2.deinit()
    tim5.deinit()
    tim14.deinit()
    listb = list(buf)
    listb.pop(0)
    print(str(listb[0]) + str(listb[1]) + str(listb[2]) + str(listb[3]) + str(listb[4]))
    if (listb[0] + listb[1] + listb[2] + listb[3] + listb[4]) > 1200:
        print('Yes')
        k.append(1)
    else:
        print('no')
        k.append(0)

print(k)

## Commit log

2019-05-27 RF at 17000 Hz
2019-05-28 Adding a KiCad project
    [OpenEM.kicad_pcb, OpenEM.sch]
2019-05-31 Change to Fritzing
    [OpenEM.fzz, OpenEM.kicad_pcb, OpenEM.sch]
2019-05-31 Update Circuit: Adding aprts
    [OpenEM.fzz]
2019-06-01 Update Circuit: Fritzing part
    [OpenEM.fzz]
2019-06-01 Incluce stability data
    [Test_stability.csv]
2019-06-02 Update TODO: timers
2019-06-02 Update TODO: timer options
2019-06-02 Need to fix memory error
    [main.py]
2019-06-05 ADC and PWM timers sync
2019-06-05 Update TODO: matched ADC and PWM
2019-06-27 Add BME280 driver
2019-06-27 BME280 driver doesnt work for the pyboard
2019-07-01 Relocate logs and make waves dir
    [OpenData2_20190629_145803.csv, OpenData3_20190629_174445.csv, OpenData4_20190701_112138.csv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]
2019-07-01 Update TODO
    [out5.csv]
2019-07-02 Testing sht31 sensor
2019-07-03 Integrate temp sensor and save to file
    [Calibrate_data.csv]
2019-07-05 Plot waves and vectors
    [Calibrate_data.csv, Calibrate_data1.csv]
2019-07-06 New data
    [Calibrate2_data.csv, Calibrate3_data.csv]
2019-08-19 Container curve tests
    [Calibrate_data.csv, Calibrate_data.ods, Calibrate_data.xlsx]
2019-08-21 Temp calibrate tests
    [temp_data.csv]
2019-08-29 Temp plot 2
    [Calibrate_data.xlsx, temp_data1.csv, temp_data2.csv]
2019-08-30 Tepl plot 3+4 and graph
    [temp_data3.csv, temp_data4.csv]
2019-09-05 Cobbity Temp data
    [temp_data_cobbity.csv, temp_data_cobbity2.csv]
2019-09-06 Make detailed cobbity plots
    [temp_data1.csv, temp_data_cobbity1.csv, temp_data_cobbity2.csv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]
2019-09-12 Apply temp to sft
    [Cobbity9_run2.csv, temp_data4.csv]
2019-09-16 Temp tests 5 and 6
    [Cobbity9_run2.csv, temp_data5.csv, temp_data6.csv]
2019-09-25 Lara data
    [Lara1.csv, lara_data1.csv, lara_data2.csv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]
2019-09-26 Lara data 4&5
    [OpenEM_data.csv, RF_calibrate.csv, lara_data3.csv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]
2019-10-01 Add RF calibrate data
    [RF_calibrate1.csv, RF_calibrate2.csv, RF_calibrate3.csv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]
2019-10-02 More tests and plots
    [FR_range.csv, OpenEM_data.csv, RF_calibrate10.csv]
2019-10-30 New data RF 11
    [OpenEM_data.csv, RF_calibrate.csv, RF_calibrate11.csv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]
2019-11-13 Attempt to calibrate HP with team at RF
    [HPcal.csv, OpenEM_data.csv]
